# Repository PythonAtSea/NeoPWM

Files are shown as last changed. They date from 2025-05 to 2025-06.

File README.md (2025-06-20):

# NeoPWM
### The best led controller for FTC
> [!NOTE]
> This is a [Highway](https://highway.hackclub.com) project, if you're here from slack (or just want to see the process of development) see [JOURNAL.md](https://github.com/PythonAtSea/NeoPWM/blob/main/JOURNAL.md), for the BOM see [BOM.md](https://github.com/PythonAtSea/NeoPWM/blob/main/BOM.md)

> [!CAUTION]
> Curently the PCB has the USB data lines swapped, will fix soon™

##### What is it?
The NeoPWM is a PWM controlled, USB-C powered, highly configurable SK6812/WS2801 (NeoPixel) controller designed for the _FIRST_ Tech Challenge (FTC). It will have a web based tool to generate configuration files and send over a serial interface. It will have poweron and PWM signal loss states, which allow led patterns to be triggered after a match and during the transition period. It also has a optional intergrated LED panel with 12 SK6812 LEDs, which will have prebuilt patterns. 
##### Why did I make it?
In FTC, there was never a great way to control LEDs. YOu could control a strip of leds over I2C using a [I2C to NeoPixel driver](https://www.adafruit.com/product/5766), but the I2C ports on the [REV Control Hub ](https://www.revrobotics.com/rev-31-1595/) are slow, which ruins your loop times which causes problems with odometry. You could use the [REV Blinkin](https://www.revrobotics.com/rev-11-1105/)
 (no that's not a typo) which is controlled over I2C, but you can't do any configuration and it's powered from the main robot battery. The NeoPWM can be powered from a external USB-C battery and will have a web tool to configure the patterns, and it will have a intergrated LED panel like the [CTRE CANdle](https://store.ctr-electronics.com/products/candle), but it will be optional, saving costs for teams who just want a LED strip.
 
**NeoPWM in default configuration without LED panel.**



**NeopPWM with intergrated LED panel**



**Both PCBs connected with 2mm mousebites**



**Main schematic**



**RP2040 circuitry schematic**



## BOM
| Name | Link | Price |
| --- | ---| --: |
| PCB | N/A | $2.00 |
| PCB Assembly | N/A | $31.64 |
| JLC Shipping | N/A | $52.31 |
| JLC Total | N/A | $76.95 |
| JST PH Connector | https://www.digikey.com/en/products/detail/jst-sales-america-inc/S3B-PH-K-S/926627 | $1.31 |
| DuPont connector | https://www.digikey.com/en/products/detail/amphenol-cs-fci/68604-403HLF/5206799 | $1.15 |
| Sk6812 Strip | https://www.digikey.com/en/products/detail/dfrobot/FIT0750/14322609 | $23.62 |
| DigiKey Shipping | N/A | $6.99 |
| DigiKey Total | N/A | $37.91 |
| M2 Screws | https://www.aliexpress.com/item/3256806025233809.html | $1.34 |
| M2 Standoffs | https://www.aliexpress.com/item/3256804631738035.html | $2.46 |
| Aliexpress Total | N/A | $3.80 |

> [!CAUTION]
> This project has not been built physically, so it may or may not work as intended.

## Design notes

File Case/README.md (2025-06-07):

- Bottom: common part between both version
- Top: only used on version without LED panel
- Top with panel: only used on version with LED panel
- Clear panel: Optional, only used on version with LED panel

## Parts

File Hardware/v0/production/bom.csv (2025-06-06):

Designator | Footprint | Quantity | Value | LCSC Part #
C1, C2 | 0402 | 2 | 10u | C15525
C10, C3 | 0402 | 2 | 1u | C52923
C11, C12, C13, C14, C17, C18, C19, C20, C21, C22, C23, C24, C25, C26, C27, C28, C4, C5, C6, C7, C8, C9 | 0402 | 22 | 100n | C1525
C15, C16 | 0402 | 2 | 15p | C1548
C29 | 1206 | 1 | 100u | C15008
D1, D10, D11, D12, D2, D3, D4, D5, D6, D7, D8, D9 | LED_SK6812_PLCC4_5.0x5.0mm_P3.2mm | 12 | SK6812 | C5380878
J1 | HRO_TYPE-C-31-M-12 | 1 | TYPE-C-31-M-12 | C165948
MOUSE-BITE-2MM-SLOT_3, MOUSE-BITE-2MM-SLOT_2, MOUSE-BITE-2MM-SLOT | mouse-bite-2mm-slot | 3 | VAL**
R1, R2 | 0402 | 2 | 5.1k | C25905
R3, R4 | 0402 | 2 | 1k | C11702
R5 | 0402 | 1 | 470 | C25117
R6 | 0402 | 1 | 4.7k | C25900
R7, R8 | 0402 | 2 | 27 | C25100
R9 | 0402 | 1 | 10k | C25744
SW1 | SW_TS-1088_XNP-L | 1 | SW_Push | C720477
U1 | RP2040-QFN-56 | 1 | RP2040 | C2040
U2 | SOT-223-3_TabPin2 | 1 | NCP1117-3.3_SOT223 | C26537
U3 | SOIC-8_5.3x5.3mm_P1.27mm | 1 | W25Q128JVS | C97521
U4 | LTV-357T_LTO | 1 | LTV-357T | C119089
X1 | ABM8-272-T3_ABR | 1 | ABM8-272-T3 | C20625731

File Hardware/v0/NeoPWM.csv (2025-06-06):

Reference | Qty | Value | DNP | Exclude from BOM | LCSC | Footprint | Exclude from Board | Datasheet
C1,C2 | 2 | 10u |  |  | C15525 | Capacitor_SMD:C_0402_1005Metric |  | ~
C3,C10 | 2 | 1u |  |  | C52923 | Capacitor_SMD:C_0402_1005Metric |  | ~
C4,C5,C6,C7,C8,C9,C11,C12,C13,C14,C17,C18,C19,C20,C21,C22,C23,C24,C25,C26,C27,C28 | 22 | 100n |  |  | C1525 | Capacitor_SMD:C_0402_1005Metric |  | ~
C15,C16 | 2 | 15p |  |  | C1548 | Capacitor_SMD:C_0402_1005Metric |  | ~
C29 | 1 | 100u |  |  | C15008 | Capacitor_SMD:C_1206_3216Metric |  | ~
D1,D2,D3,D4,D5,D6,D7,D8,D9,D10,D11,D12 | 12 | SK6812 |  |  | C5380878 | LED_SMD:LED_SK6812_PLCC4_5.0x5.0mm_P3.2mm |  | https://cdn-shop.adafruit.com/product-files/1138/SK6812+LED+datasheet+.pdf
H1,H2,H3,H4,H5,H6,H7,H8 | 8 | MountingHole_Pad |  | Excluded from BOM |  | MountingHole:MountingHole_2.2mm_M2_Pad |  | ~
J1 | 1 | TYPE-C-31-M-12 |  |  | C165948 | usb-c:HRO_TYPE-C-31-M-12
J2 | 1 | PWM Input |  | Excluded from BOM |  | Connector_JST:JST_PH_S3B-PH-K_1x03_P2.00mm_Horizontal |  | ~
J3 | 1 | NeoPixel Connector |  | Excluded from BOM |  | Connector_JST:JST_PH_S3B-PH-K_1x03_P2.00mm_Horizontal |  | ~
J4 | 1 | Light Bar Connector (main) |  | Excluded from BOM |  | Connector_PinHeader_2.54mm:PinHeader_1x03_P2.54mm_Vertical |  | ~
J5 | 1 | Light Bar Connector (daughter) | DNP | Excluded from BOM |  | Connector_PinSocket_2.54mm:PinSocket_1x03_P2.54mm_Vertical |  | ~
R1,R2 | 2 | 5.1k |  |  | C25905 | Resistor_SMD:R_0402_1005Metric |  | ~
R3,R4 | 2 | 1k |  |  | C11702 | Resistor_SMD:R_0402_1005Metric |  | ~
R5 | 1 | 470 |  |  | C25117 | Resistor_SMD:R_0402_1005Metric |  | ~
R6 | 1 | 4.7k |  |  | C25900 | Resistor_SMD:R_0402_1005Metric |  | ~
R7,R8 | 2 | 27 |  |  | C25100 | Resistor_SMD:R_0402_1005Metric |  | ~
R9 | 1 | 10k |  |  | C25744 | Resistor_SMD:R_0402_1005Metric |  | ~
SW1 | 1 | SW_Push |  |  | C720477 | TS-1088-AR02016:SW_TS-1088_XNP-L |  | ~
U1 | 1 | RP2040 |  |  | C2040 | RP2040_minimal_r2:RP2040-QFN-56
U2 | 1 | NCP1117-3.3_SOT223 |  |  | C26537 | Package_TO_SOT_SMD:SOT-223-3_TabPin2 |  | http://www.onsemi.com/pub_link/Collateral/NCP1117-D.PDF
U3 | 1 | W25Q128JVS |  |  | C97521 | Package_SO:SOIC-8_5.3x5.3mm_P1.27mm |  | https://www.winbond.com/resource-files/w25q128jv_dtr%20revc%2003272018%20plus.pdf
U4 | 1 | LTV-357T |  |  | C119089 | LTV-357T:LTV-357T_LTO |  | https://www.buerklin.com/medias/sys_master/download/download/h91/ha0/8892020588574.pdf
X1 | 1 | ABM8-272-T3 |  |  | C20625731 | footprints:ABM8-272-T3_ABR |  | ABM8-272-T3

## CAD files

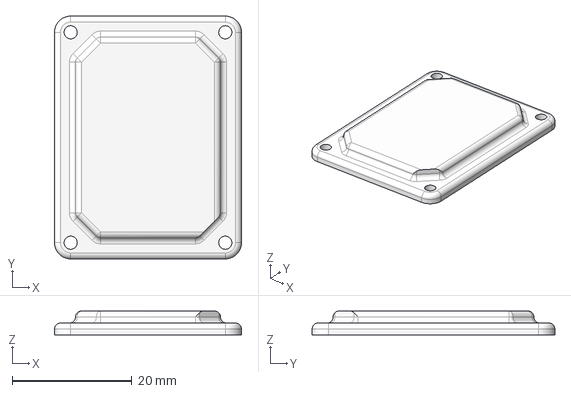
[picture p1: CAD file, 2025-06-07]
Case/Clear panel.step
31.2 x 40.5 x 4.00 mm

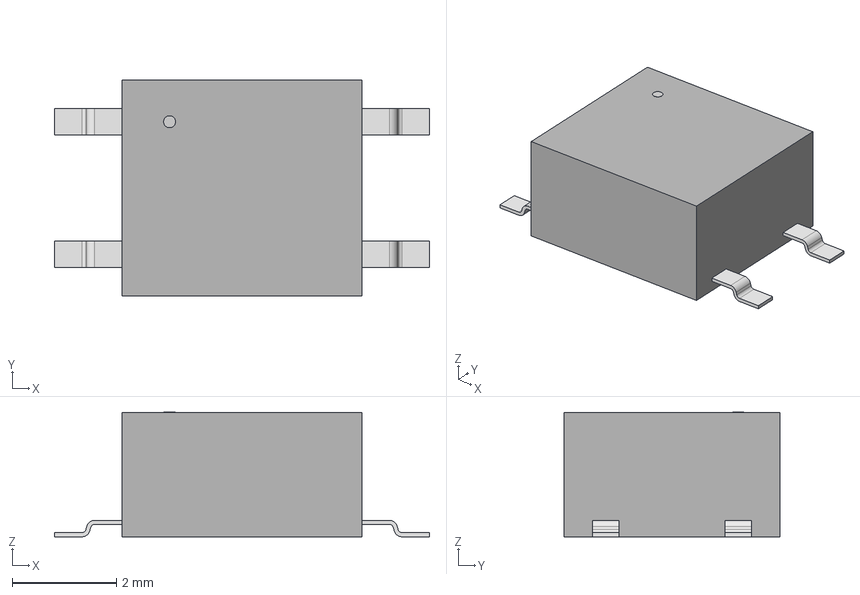
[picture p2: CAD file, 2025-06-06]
Hardware/v0/Footprints/3d_models/LTV-357T_LTO.step
7.19 x 4.14 x 2.39 mm

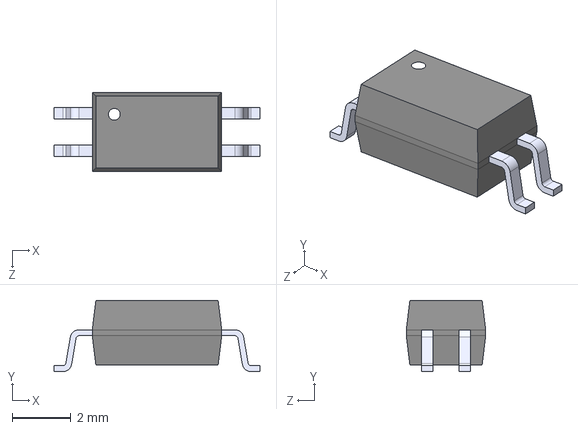
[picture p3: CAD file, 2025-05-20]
Hardware/v0/Footprints/LTV-217-B-G/LTV-217-B-G.step
7.00 x 2.42 x 2.70 mm

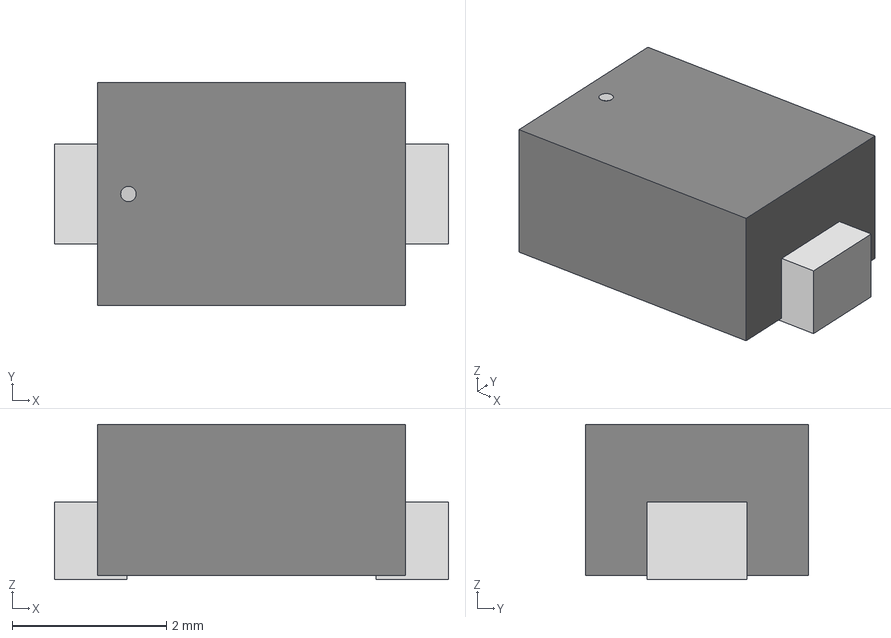
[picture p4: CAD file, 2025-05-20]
Hardware/v0/Footprints/TS-1088-AR02016/SW_TS-1088_XNP.step
5.11 x 2.90 x 2.01 mm

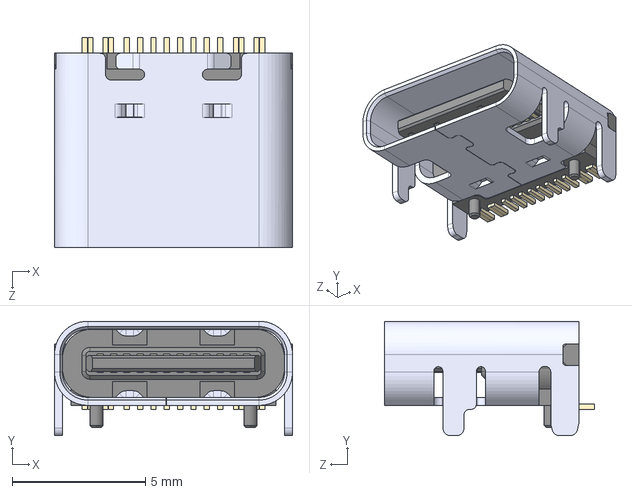
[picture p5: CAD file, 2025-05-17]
Hardware/v0/Footprints/usb-c/TYPE-C-31-M-12.step
8.94 x 4.30 x 7.90 mm

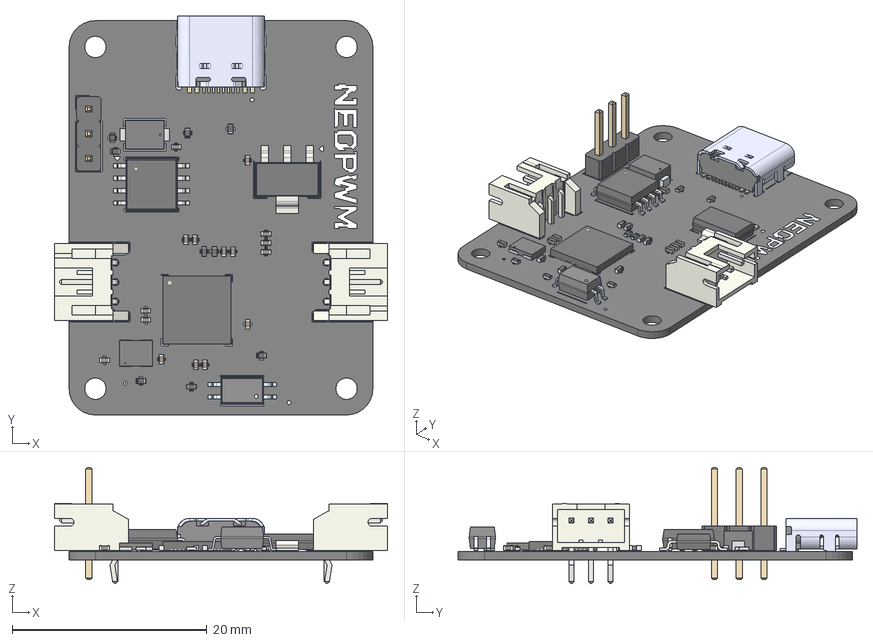
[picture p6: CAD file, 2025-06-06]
Hardware/v0/NeoPWM.step
34.2 x 41.0 x 11.9 mm
C_0402_1005Metric x 16
PinHeader_1x03_P2.54mm_Vertical
SOT-223
R_0402_1005Metric x 9
JST_PH_S3B-PH-K_1x03_P2.00mm_Horizontal x 2
QFN-56-1EP_7x7mm_P0.4mm_EP5.6x5.6mm
LTV-217-B-G
ABM8-272-T3_ABR
SW_TS-1088_XNP
SOIC-8_5.3x5.3mm_P1.27mm
TYPE-C-31-M-12
NeoPWM_silkscreen
NeoPWM_PCB

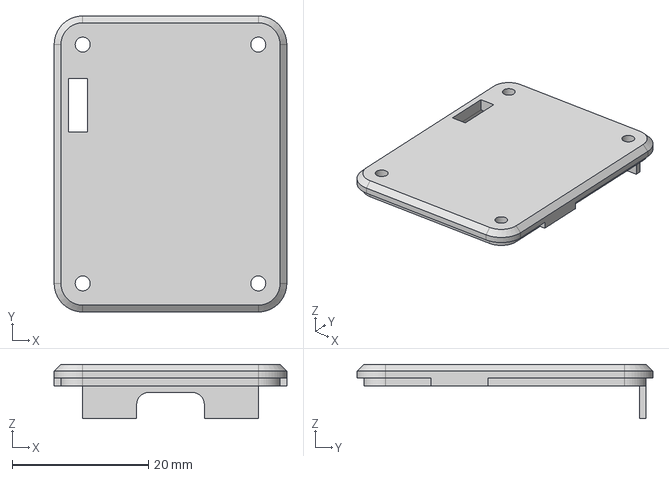
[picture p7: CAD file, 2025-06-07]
Case/Top with panel.step
34.2 x 43.5 x 8.00 mm

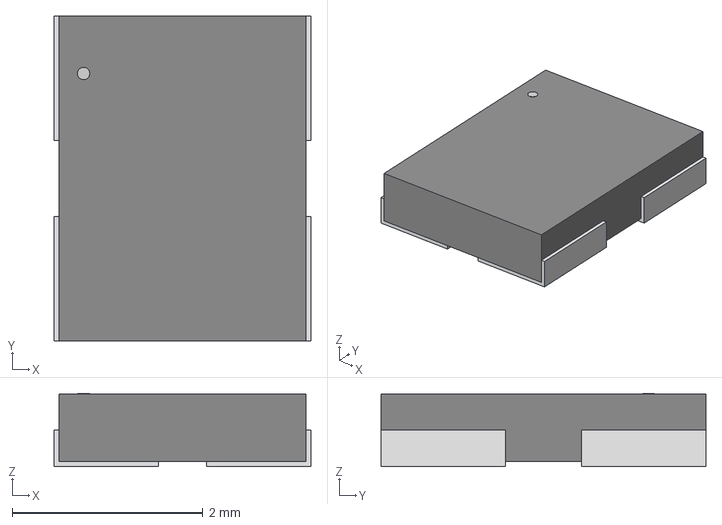
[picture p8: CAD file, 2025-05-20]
Hardware/v0/Footprints/3d_models/ABM8-272-T3_ABR.step
2.69 x 3.40 x 0.765 mm

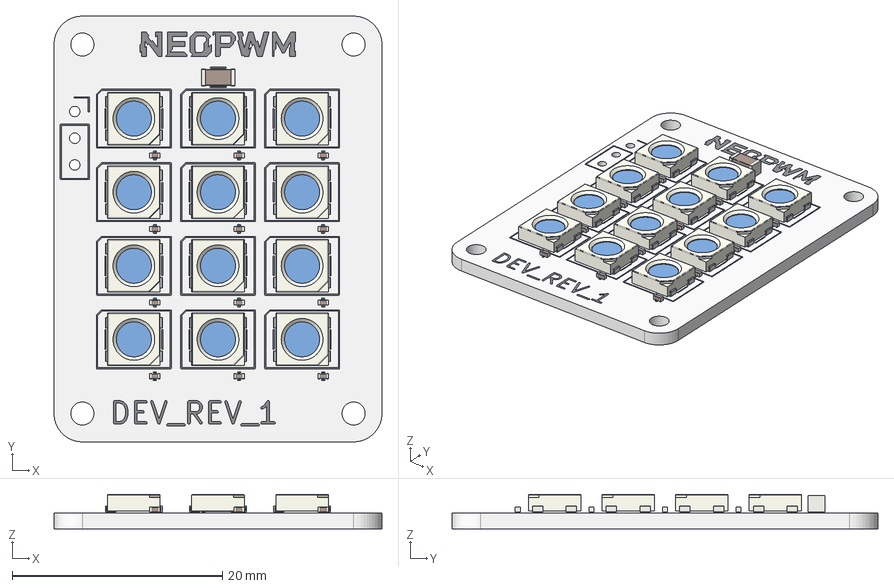
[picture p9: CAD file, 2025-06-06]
Hardware/v0/NeoPWM_daughter.step
31.2 x 40.5 x 3.37 mm
LED_SK6812_PLCC4_5.0x5.0mm_P3.2mm x 12
C_0402_1005Metric x 12
C_1206_3216Metric
NeoPWM_silkscreen
NeoPWM_PCB

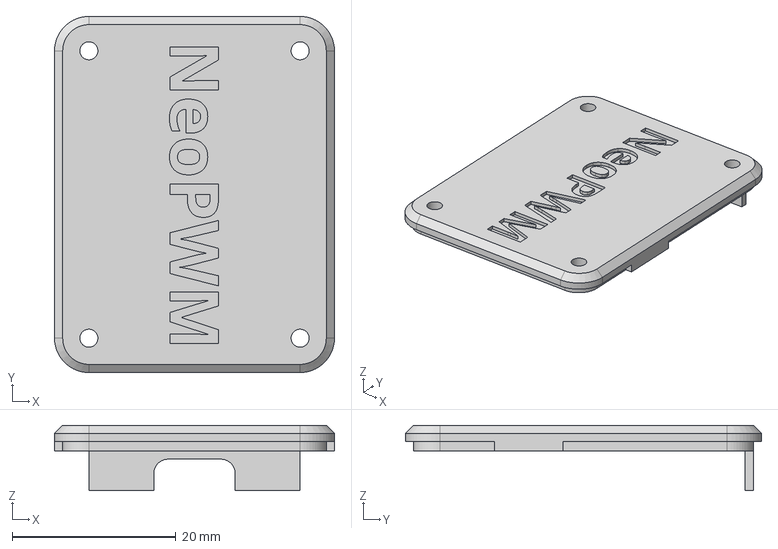
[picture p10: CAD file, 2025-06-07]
Case/Top.step
34.2 x 43.5 x 8.00 mm

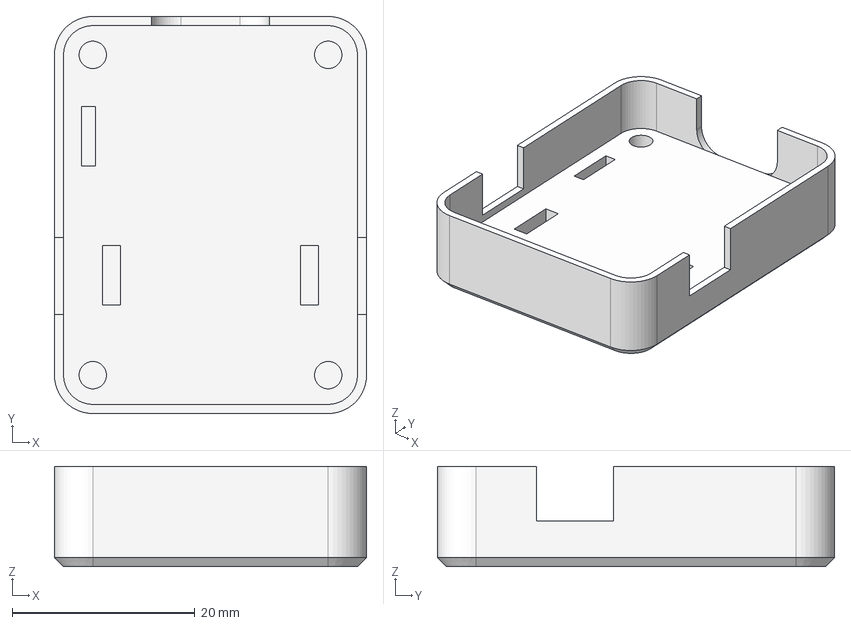
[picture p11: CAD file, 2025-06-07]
Case/Bottom.step
34.2 x 43.5 x 11.0 mm

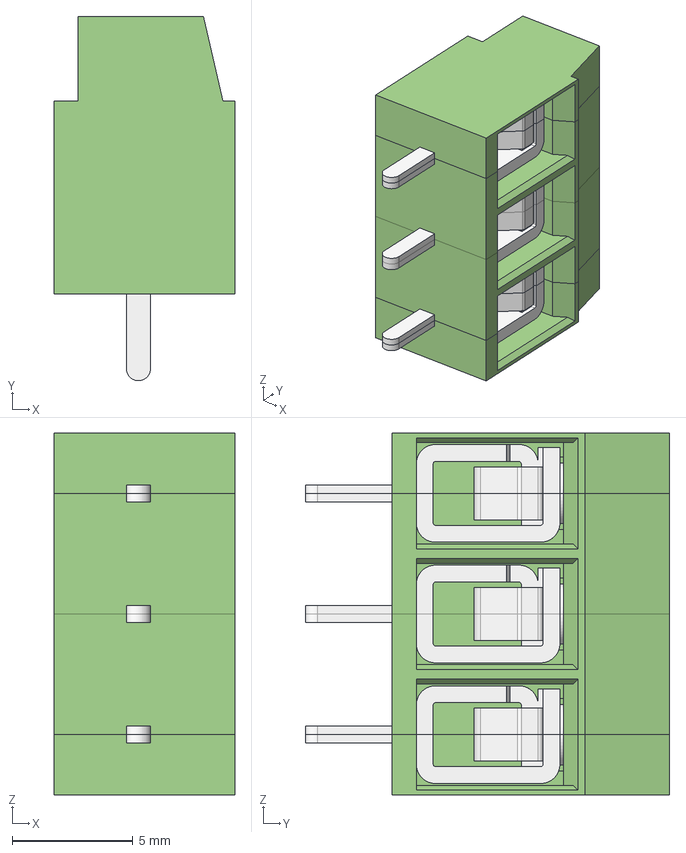
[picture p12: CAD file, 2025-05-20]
Hardware/v0/Footprints/691137710003/691137710003.step
7.50 x 15.1 x 15.0 mm
MRT12P5_SX
MRT12P5_CNT x 2
MRT12P5_DX

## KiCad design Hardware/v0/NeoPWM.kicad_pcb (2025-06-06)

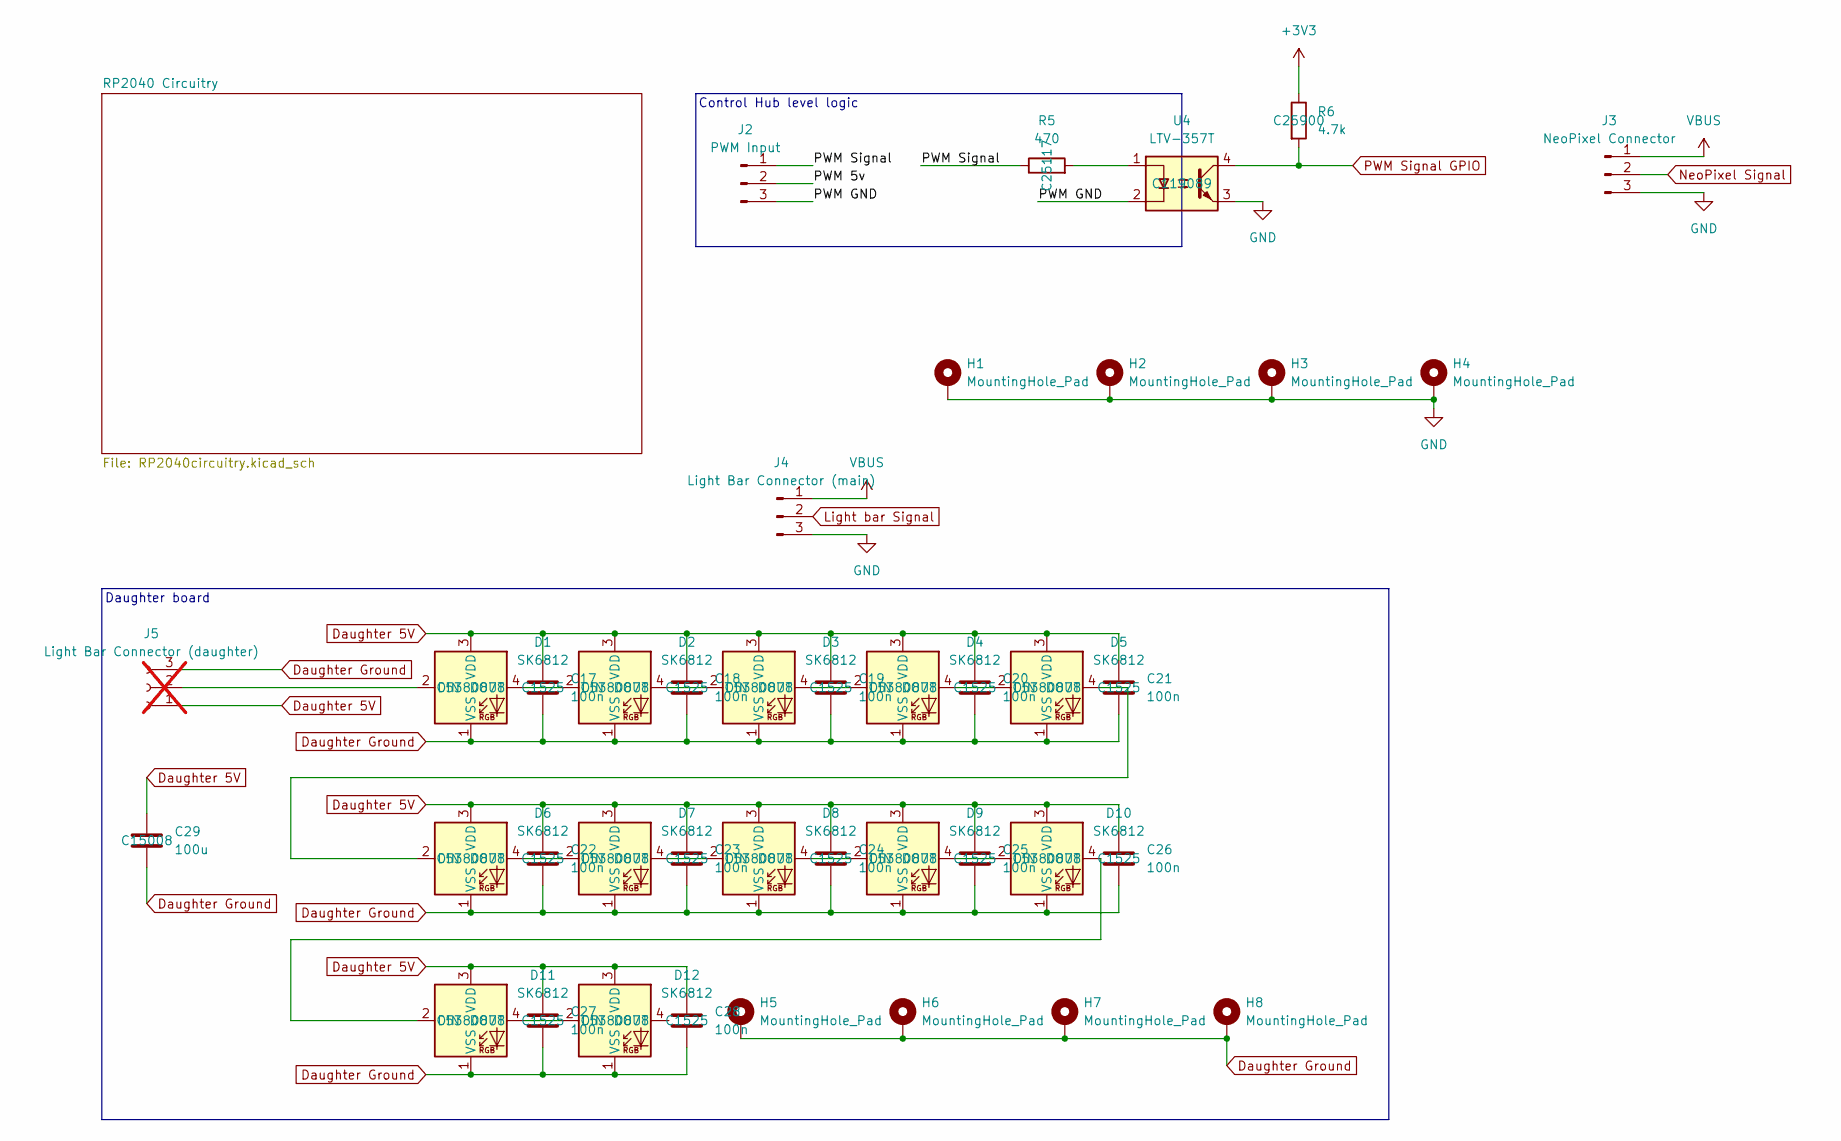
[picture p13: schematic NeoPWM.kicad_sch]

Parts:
C17, C18, C19, C20, C21, C22, C23, C24, C25, C26, C27, C28: 100n; C_0402_1005Metric; LCSC C1525
C29: 100u; C_1206_3216Metric; LCSC C15008
D1, D2, D3, D4, D5, D6, D7, D8, D9, D10, D11, D12: SK6812; LED_SK6812_PLCC4_5.0x5.0mm_P3.2mm; LCSC C5380878
H1, H2, H3, H4, H5, H6, H7, H8: MountingHole_Pad; MountingHole_2.2mm_M2_Pad
J2: PWM Input; JST_PH_S3B-PH-K_1x03_P2.00mm_Horizontal
J3: NeoPixel Connector; JST_PH_S3B-PH-K_1x03_P2.00mm_Horizontal
J4: Light Bar Connector (main); PinHeader_1x03_P2.54mm_Vertical
J5: Light Bar Connector (daughter); PinSocket_1x03_P2.54mm_Vertical; not fitted
R5: 470; R_0402_1005Metric; LCSC C25117
R6: 4.7k; R_0402_1005Metric; LCSC C25900
U4: LTV-357T; LTV-357T_LTO; LCSC C119089

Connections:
+3V3: R6.1; also elsewhere on the board
/PWM 5v: J2.2
/PWM GND: J2.3, U4.2
/PWM Signal: J2.1, R5.1
Daughter 5V: C17.1, C18.1, C19.1, C20.1, C21.1, C22.1, C23.1, C24.1, C25.1, C26.1, C27.1, C28.1, C29.1, D1.3 (VDD), D2.3 (VDD), D3.3 (VDD), D4.3 (VDD), D5.3 (VDD), D6.3 (VDD), D7.3 (VDD), D8.3 (VDD), D9.3 (VDD), D10.3 (VDD), D11.3 (VDD), D12.3 (VDD), J5.1
Daughter Ground: C17.2, C18.2, C19.2, C20.2, C21.2, C22.2, C23.2, C24.2, C25.2, C26.2, C27.2, C28.2, C29.2, D1.1 (VSS), D2.1 (VSS), D3.1 (VSS), D4.1 (VSS), D5.1 (VSS), D6.1 (VSS), D7.1 (VSS), D8.1 (VSS), D9.1 (VSS), D10.1 (VSS), D11.1 (VSS), D12.1 (VSS), H5.1, H6.1, H7.1, H8.1, J5.3
GND: H1.1, H2.1, H3.1, H4.1, J3.3, J4.3, U4.3; also elsewhere on the board
Light bar Signal: J4.2; also elsewhere on the board
NeoPixel Signal: J3.2; also elsewhere on the board
unnamed: D1.2 (DIN), J5.2
unnamed: D1.4 (DOUT), D2.2 (DIN)
unnamed: D2.4 (DOUT), D3.2 (DIN)
unnamed: D3.4 (DOUT), D4.2 (DIN)
unnamed: D4.4 (DOUT), D5.2 (DIN)
unnamed: D5.4 (DOUT), D6.2 (DIN)
unnamed: D6.4 (DOUT), D7.2 (DIN)
unnamed: D7.4 (DOUT), D8.2 (DIN)
unnamed: D8.4 (DOUT), D9.2 (DIN)
unnamed: D9.4 (DOUT), D10.2 (DIN)
unnamed: D10.4 (DOUT), D11.2 (DIN)
unnamed: D11.4 (DOUT), D12.2 (DIN)
unnamed: R5.2, U4.1
PWM Signal GPIO: R6.2, U4.4; also elsewhere on the board
VBUS: J3.1, J4.1; also elsewhere on the board

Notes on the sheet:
Daughter board
Control Hub level logic

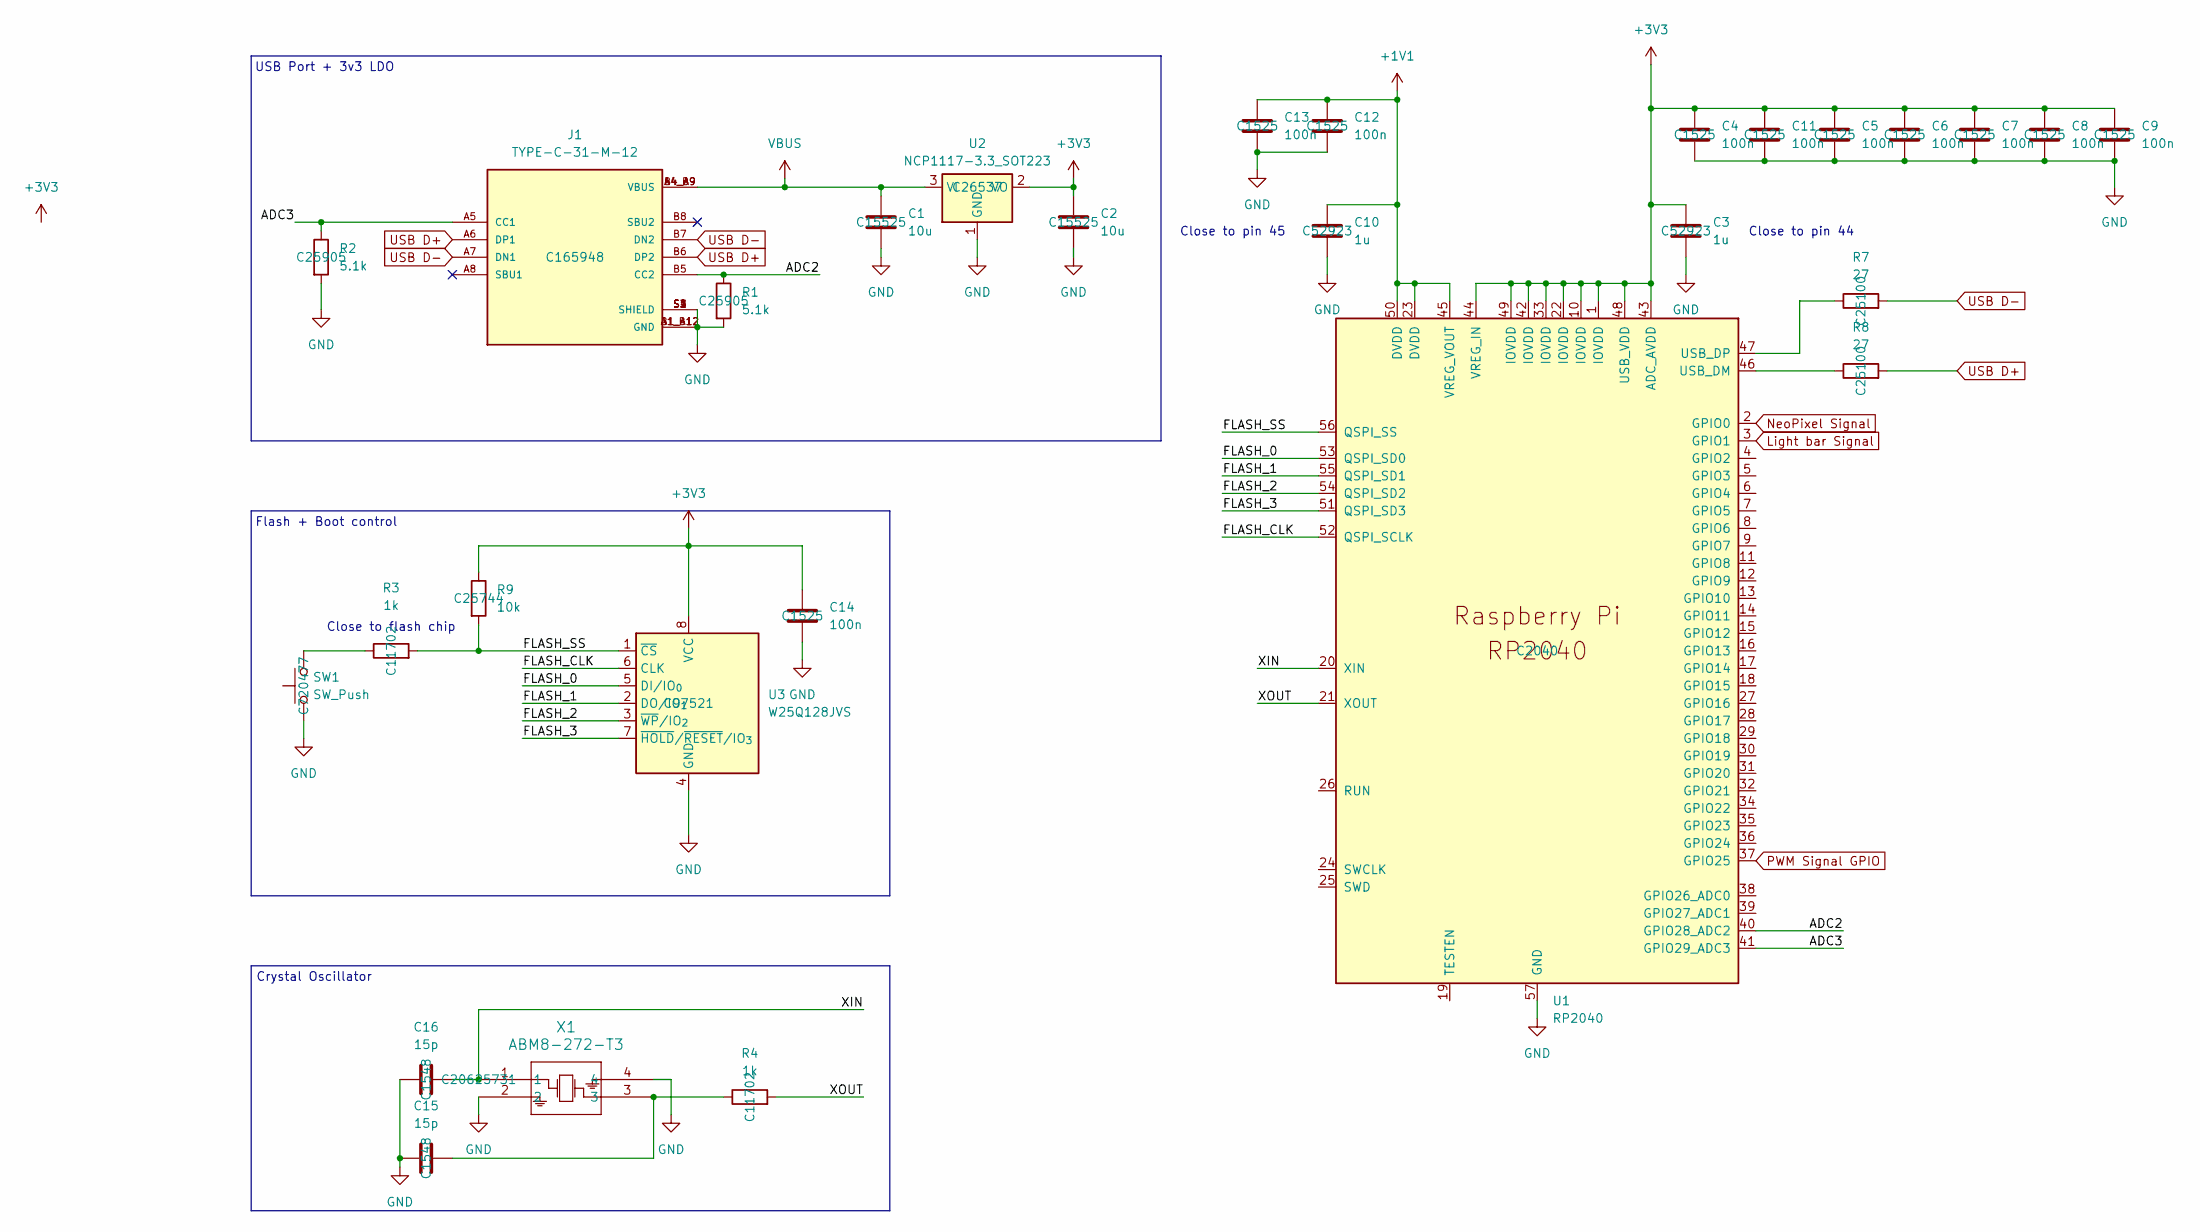
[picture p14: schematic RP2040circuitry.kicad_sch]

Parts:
C1, C2: 10u; C_0402_1005Metric; LCSC C15525
C3, C10: 1u; C_0402_1005Metric; LCSC C52923
C4, C5, C6, C7, C8, C9, C11, C12, C13, C14: 100n; C_0402_1005Metric; LCSC C1525
C15, C16: 15p; C_0402_1005Metric; LCSC C1548
J1: TYPE-C-31-M-12; HRO_TYPE-C-31-M-12; PARTREV 2020.12.08; LCSC C165948
R1, R2: 5.1k; R_0402_1005Metric; LCSC C25905
R3, R4: 1k; R_0402_1005Metric; LCSC C11702
R7, R8: 27; R_0402_1005Metric; LCSC C25100
R9: 10k; R_0402_1005Metric; LCSC C25744
SW1: SW_Push; SW_TS-1088_XNP-L; LCSC C720477
U1: RP2040; RP2040-QFN-56; LCSC C2040
U2: NCP1117-3.3_SOT223; SOT-223-3_TabPin2; LCSC C26537
U3: W25Q128JVS; SOIC-8_5.3x5.3mm_P1.27mm; LCSC C97521
X1: ABM8-272-T3; ABM8-272-T3_ABR; LCSC C20625731

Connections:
+1V1: C10.1, C12.1, C13.1, U1.23 (DVDD), U1.45 (VREG_VOUT), U1.50 (DVDD)
+3V3: C2.1, C3.1, C4.1, C5.1, C6.1, C7.1, C8.1, C9.1, C11.1, C14.1, R9.1, U1.1 (IOVDD), U1.10 (IOVDD), U1.22 (IOVDD), U1.33 (IOVDD), U1.42 (IOVDD), U1.43 (ADC_AVDD), U1.44 (VREG_IN), U1.48 (USB_VDD), U1.49 (IOVDD), U2.2 (VO), U3.8 (VCC); also elsewhere on the board
/RP2040 Circuitry/ADC2: J1.B5 (CC2), R1.1, U1.40 (GPIO28_ADC2)
/RP2040 Circuitry/ADC3: J1.A5 (CC1), R2.1, U1.41 (GPIO29_ADC3)
/RP2040 Circuitry/FLASH_0: U1.53 (QSPI_SD0), U3.5 (DI/IO_{0})
/RP2040 Circuitry/FLASH_1: U1.55 (QSPI_SD1), U3.2 (DO/IO_{1})
/RP2040 Circuitry/FLASH_2: U1.54 (QSPI_SD2), U3.3 (~WP/IO_{2})
/RP2040 Circuitry/FLASH_3: U1.51 (QSPI_SD3), U3.7 (~HOLD/~RESET/IO_{3})
/RP2040 Circuitry/FLASH_CLK: U1.52 (QSPI_SCLK), U3.6 (CLK)
/RP2040 Circuitry/FLASH_SS: R3.2, R9.2, U1.56 (QSPI_SS), U3.1 (~CS)
/RP2040 Circuitry/XIN: C16.2, U1.20 (XIN), X1.1
/RP2040 Circuitry/XOUT: R4.2, U1.21 (XOUT)
GND: C1.2, C2.2, C3.2, C4.2, C5.2, C6.2, C7.2, C8.2, C9.2, C10.2, C11.2, C12.2, C13.2, C14.2, C15.1, C16.1, J1.A1_B12 (GND), J1.B1_A12 (GND), J1.S1 (SHIELD), J1.S2 (SHIELD), J1.S3 (SHIELD), J1.S4 (SHIELD), R1.2, R2.2, SW1.1, U1.57 (GND), U2.1 (GND), U3.4 (GND), X1.2, X1.4; also elsewhere on the board
Light bar Signal: U1.3 (GPIO1); also elsewhere on the board
NeoPixel Signal: U1.2 (GPIO0); also elsewhere on the board
unnamed: C15.2, R4.1, X1.3
unnamed: R3.1, SW1.2
unnamed: R8.1, U1.46 (USB_DM)
unnamed: R7.1, U1.47 (USB_DP)
PWM Signal GPIO: U1.37 (GPIO25); also elsewhere on the board
USB D+: J1.A6 (DP1), J1.B6 (DP2), R8.2
USB D-: J1.A7 (DN1), J1.B7 (DN2), R7.2
VBUS: C1.1, J1.A4_B9 (VBUS), J1.B4_A9 (VBUS), U2.3 (VI); also elsewhere on the board

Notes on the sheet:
USB Port + 3v3 LDO
Close to pin 45
Close to flash chip
Crystal Oscillator
Flash + Boot control
Close to pin 44

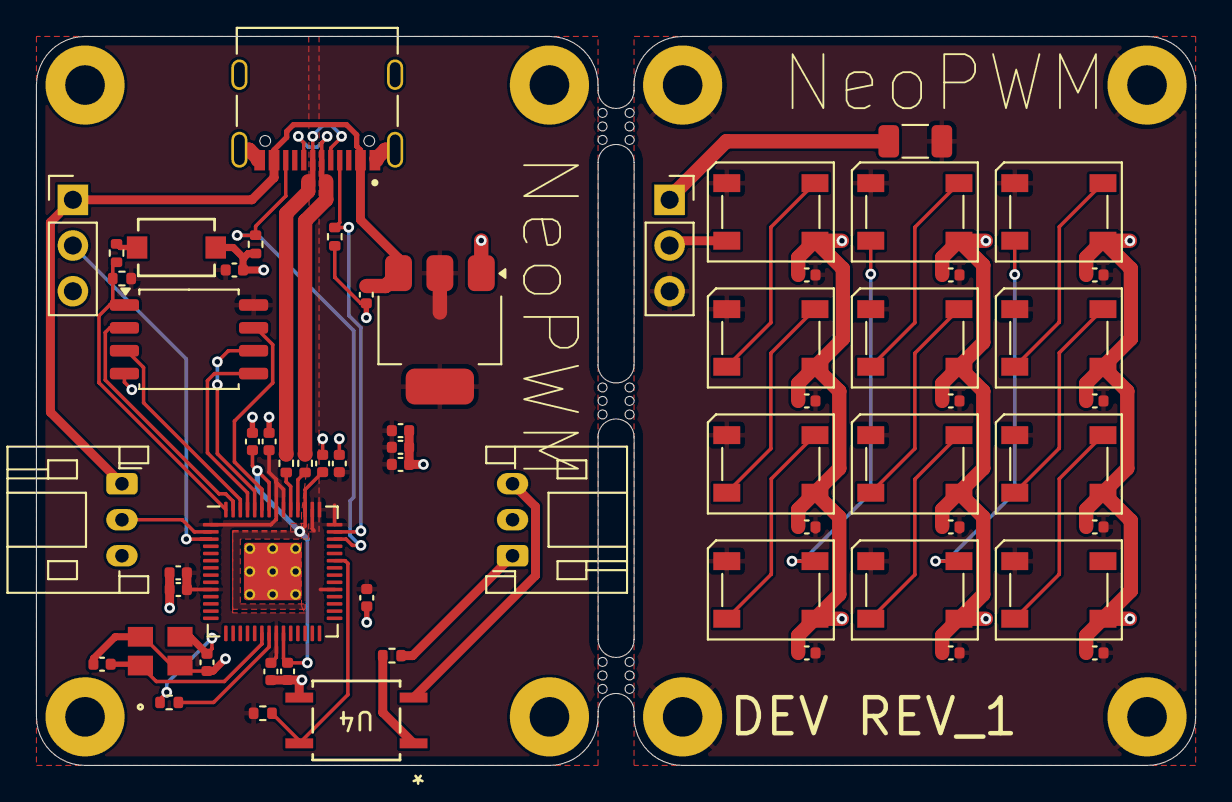
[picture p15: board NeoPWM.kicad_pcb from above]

Board: 2 copper layers, 64.4 x 40.5 mm, 72 parts (0 on the bottom side), 40 nets.

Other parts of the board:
mouse-bite-2mm-slot, mouse-bite-2mm-slot#2, mouse-bite-2mm-slot#3: VAL**; mouse-bite-2mm-slot

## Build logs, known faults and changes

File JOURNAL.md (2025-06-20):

---
title: "NeoPWM"
author: "Hudson"
description: "The best LED controller in FTC"
created_at: "2024-03-17"
---
# NeoPWM, the best LED controller in *FTC*
## Non-obvious TODO
- ~~Connect the NeoPixel, PWM, and CC data lines to pins on the rp2040 that makes sense.~~
- ~~Add mounting holes to the PCB~~
- ~~Make second PCB for intergrated led panel~~

## Total time: 32 hours

## 5/17/25, 4 hours
### General Idea
In the *FIRST* Tech Challenge, people often want LEDs on their robot for driver feedback and for looks. There isn't a great way to control neopixel, because I²C is *really* slow. REV made the [REV Blinkin](https://www.revrobotics.com/rev-11-1105/), which allows for control over PWM, but you can't do very much configuartion, and you have to run it on the main robot battery. For high level teams with tons of other devices, this isn't feasible. The NeoPWM will allow for advanced configuration over USB, super fast control using PWM, and power using a 5V USB power bank. 
overall diagram
### *FTC* Rule stuff
Because there will be two ground planes (the robot battery and the USB battery), I will need to use a optocoupler to pass the PWM signal to the MCU, which will be powered by the USB battery. Because it contains a programable MCU, in order for it to be legal, it needs to be a Commercial Off the Shelf (COTS) component, so essentially I need to design it, and then sell it and get a EIN and a bunch of annoying legal paperwork. :sob:
### USB-C Port
I want to use a USB-C port for firmware updates and such, as well as for power during standard operations. I think the [TYPE-C-31-M-12](https://jlcpcb.com/partdetail/Korean_HropartsElec-TYPE_C_31_M12/C165948) by Korean Hroparts Elec might be a decent option, it supports USB 2.0 and basic power mode config, so I can pull 15w of power by pulling CC1 and CC2 to ground.
### MCU
I think that a RP2040 is probably the right choice, given the amazing documatation and community support. It's also pretty cheap on JLC, being less than a dollar if you order more than 10. 
### KiCAD VCS
KiCAD 9.0 supports git, so I can just make the NeoPWM the base folder for the KiCAD project. Yay!
### Starting on the schematic
I started working on the RP2040 part of the device, and finshing the power input, USB-C port, the crystal oscillator, and the 16Mb flash module (which is a basic part on JLC yay!)
schematic

## 5/19/25, 5 hours
### Power (ahhhhhhh)
Leds consume a *lot* of power. I want to support using a USB-C battery bank, which should allow this to have minimal performance impact. To do this I have 2 options, use USB PD or pull the CC pins to ground with 5.1kΩ resistors. Using USB PD would allow for a lot of power, up to 5a at 12v = 60w, but it is also very complicated and expensive to implement. The simpler only supplies 3a at 5v = 15w, but that is enough to power 50 leds at full white which should be enough. I will add a software system to manage the power used to ensure it stays below 15w by dimming the LEDs, but this seems like the best idea.
### Optocoupler
I have elected use the LTV-357T for passing the PWM signal from the control hub ground level to the rp2040 ground level, mainly due it's availability on JLC. 
optocoupler
### Bom
I went through and got most of the BOM done, still need to add whatever parts I'm gonna be using for the case though. Also whatever parts I realize I need to add in a week.
### 3D Models
I've started to add 3D models to some of the footprints that don't have them, this is mianly to assist in making the case down the road (wow im thinking about future self thats crazy)

screwterminal
allmodels

### Done with schematic!
I finished the schematic, assigned all the footprints, and made sure it transferred without issue!!

## 5/20/25, 4 hours
### First pass of PCB
I made my first pass of routing the PCB, although there's still a bunch of tiny things i need to do, as well as fixing a *bunch* of DRC errors


### Optocoupler swap
I swapped the optocoupler for the [LTV-217-B-G](https://jlcpcb.com/partdetail/liteon-LTV_217_BG/C115450), mainly cause it's a bsic part of JLC, which saves $3. Also it's a SMD part, which makes case design easier because I don't have stuff sticking out of the bottom of the board.

### PCB general layout done
I finished the general layout of the PCB, still need to add mounting holes and a reset button. Still conflicted on whether on not to add a status led. Also KiCAD's 3D view looks soooo cool with raytracing on!

Raytraced
### Mounting holes
I added some M2 mounting holes, these will attach the PCB to the 3D printed case!



## 6/1/25, 4 hours
### Minor tweaks
Moved the oscillator around to save some space. Debating whether or not to move the PWM signal input over to save space and make the pcb smaller (and cheaper).


### Less minor tweaks
Moved the mounting holes to be in the corners and added a USB-C cable keepout zone. Also added some silkscreen stuff!




## 6/2/25, 6 hours
### I/O layout changes
I decided to move the led output to the left side and the PWM input to the right side to save space. This also allows it to fit into a piece of [GoBilda channel](https://www.gobilda.com/1120-series-u-channel-1-hole-48mm-length/), a very common build system in FTC. I also made a first draft of the case, but realized I was gonna have to completely remake it to account the led panel I have yet to make (probably gonna do that today)


### More I/O layout tweaks
I moved the USB-C port to the exact center cuz it was odd it being barely on the side. I also moved the PWM and LED connectors out 3mm to get outside of the case and make plugging stuff in easier.


### Optional LED panel
Sometime you might want a intergrated panel, like the [GoBilda RGB light](https://www.gobilda.com/rgb-indicator-light-pwm-controlled/). However, some teams would only use the LED strip, so having the panel would be useless. I could've accomplished this with a completely different 2 sided PCBA, but that would be very expensive so I decided to have a optional daughterboard which communicates via a 3 pin vertical Dupont connector.


### Very rough draft of case
I made a rough draft of the case, and realized a couple things I need to change, including the location of the daughterboard interconnect. This is because the bolt will intersect it's location, which won't work. I also learned to not directly derive stuff from the PCB CAD, because any changes to the PCB breaks _everything_


## 6/3/25, 3 hours
### Case
Originally I wanted to have m2 screws holding the top and bottom parts of the case together, but after I made a rough draft I printed it out and pressfitting it actually works quite well, so I'm probably gonna do that cuz m2 screws seem easy to mess up. I still have to make the case for the version with the intergrated light tho.

thing

## 6/4/25, 1 hour
### Standoffs
After some thought I realized this is gonnabe on a robot which is gonna experiance a lot of hard shocks, so friction fit is a terrible idea. Instead, I'm gonna use some 6mm m2 standoffs and a decently long screw.
### Moving daughterboard interconnect
In order to make space for the standoff, I need to move the interconnect. However, the flash module is in the way so I need to move that, which causes some routing issues because it's very close to the usb data lines. However, I eventually managed to make it work, but I did have to change the clearance between tracks to .15 from .2, which is fine because JLCPCB's tolerance is .1



## 6/5/25, 3 hours
### CAD
I remember why I hate doing CAD, it's so slow and tedious. However, I did eventually get the case completed, for both the versions with and without the intergrated LED panel. I'm planning on getting the clear part on the top 3D printed out of 8001 resin from JLC3DP. 



## 6/6/25, 2 hours
### Cost optimizing
Since tariffs happened, saving $5 dollars with JLC assembly actually saves $8 after tariffs. Also, shipping is _really_ expensive (around $38), and this is mainly due to weight. One thing you can do the save weight (and money) is make your pcb as small as humanly possible by putting the footprints right up each other. Additionally, if you can keep it under 100x100mm the PCB is $2. Another cool trick you can do if you have 2 boards is use mousebites and connect them togther, which means you only have to pay the PCBA setup fee once (if you're using PCBA). Using that $9 coupon saved me around $13.



## 6/19/25, 1 hour?

### ......

So I got my PCB! Then it wouldn't work with usb. Then I checked my schematic. 

so i thought about this for a bit, and eventually decided to make a "crossover" usb extension cable.  (sorrt for the bad image quality, it was taken on a 5 year old laptop webcam)

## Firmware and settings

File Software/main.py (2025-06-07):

import machine
import time
import neopixel
import ujson

with open("config.json") as f:
    config = ujson.load(f)

PWM_PIN = config["pwm_pin"]
NEOPIXEL_PIN = config["neopixel_pin"]
NUM_PIXELS = config["num_pixels"]

np = neopixel.NeoPixel(machine.Pin(NEOPIXEL_PIN), NUM_PIXELS)
pwm_pin = machine.Pin(PWM_PIN, machine.Pin.IN)

pulse_start = 0
pulse_width = 0

def pwm_callback(pin):
    global pulse_start, pulse_width
    if pin.value():
        pulse_start = time.ticks_us()
    else:
        pulse_width = time.ticks_diff(time.ticks_us(), pulse_start)

pwm_pin.irq(trigger=machine.Pin.IRQ_RISING | machine.Pin.IRQ_FALLING, handler=pwm_callback)

def pulse_to_color(pulse_us):
    pulse_clamped = max(1000, min(2000, pulse_us))
    r = int(255 * (2000 - pulse_clamped) / 1000) if pulse_clamped < 1500 else 0
    g = int(255 * (1 - abs(pulse_clamped - 1500) / 500))
    b = int(255 * (pulse_clamped - 1000) / 1000) if pulse_clamped > 1500 else 0
    return (r, g, b)

while True:
    print("PWM ", pulse_width)
    color = pulse_to_color(pulse_width)
    for i in range(NUM_PIXELS):
        np[i] = color
    np.write()
    time.sleep_ms(100)

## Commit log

2025-05-17 Add initial KiCAD project files and update JOURNAL.md with KiCAD VCS information
    [NeoPWM.kicad_pcb, NeoPWM.kicad_sch]
2025-05-17 Add KiCAD project files, update schematic and backup configurations
    [NeoPWM.kicad_sch, RP2040circuitry.kicad_sch]
2025-05-17 Rename "RP2040 stuff" to "RP2040 Circuitry" in schematic and project files
    [NeoPWM.kicad_sch]
2025-05-17 Refactor code structure and remove redundant sections for improved readability and maintainability
    [NeoPWM.kicad_pcb, RP2040circuitry.kicad_sch, TYPE-C-31-M-12.step]
2025-05-17 Added shematic changes!
    [RP2040circuitry.kicad_sch]
2025-05-17 Added schematic screenshot
2025-05-18 added crystal osccillator
    [RP2040circuitry.kicad_sch]
2025-05-19 Power + Optocoupler
    [NeoPWM.kicad_sch, RP2040circuitry.kicad_sch]
2025-05-19 BOM + footprints
    [RP2040circuitry.kicad_sch]
2025-05-20 3D Models
    [691137710003.step, NeoPWM.kicad_sch, RP2040circuitry.kicad_sch]
2025-05-20 Finished schematic
    [ABM8-272-T3_ABR.step, NeoPWM.kicad_pcb, NeoPWM.kicad_sch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]
2025-06-02 moved hardware to it's own dir
    [691137710003.step, ABM8-272-T3_ABR.step, LTV-217-B-G.step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]
2025-06-06 whoops i forgot to commit this
    [LTV-357T_LTO.step, NeoPWM.csv, NeoPWM.kicad_pcb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]
2025-06-06 fab export
    [NeoPWM.csv, NeoPWM.kicad_pcb, bom.csv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]
2025-06-07 first draft of bom
